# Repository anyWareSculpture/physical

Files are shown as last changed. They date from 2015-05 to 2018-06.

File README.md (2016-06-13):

# physical
Physical computing aspects of anyWare (firmware, electronics)

## arduino

The Arduino sketches share some common code.
However, there are no good mechanism for sharing code when using the IDE.

Our workaround for now is to keep shared code in the common/ folder
and copy the files from there into each sketch folder.
Not nice, but the result is self-contained sketches.

We use the Teensy 3.x for parts of the system. Download the Teensyduino add-on from here: https://www.pjrc.com/teensy/td_download.html
Note: We don't need any libraries installed with Teensy as we include our own.

Note: As of December 2015, our code doesn't compile with Arduino >= 1.6.6.

### Programming Info

**PanelInterface:**

The 3 panel interfaces run off separate Arduinos running the same sketch, but with different configurations.

* Open PanelInterface/configuration.h
* Enable the controller you want to program; A, B or C
* Compile & Upload
* Repeat for all controllers

### Test sketches

These are just for hardware testing

### Test games

These are basic self-contained game sketches, for playtesting in isolation

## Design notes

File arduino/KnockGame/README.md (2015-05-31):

# KnockGame

This sketch is responsible for the **Handshake** and **Knock** interfaces.

# External Libraries

## SerialCommand

https://github.com/kroimon/Arduino-SerialCommand

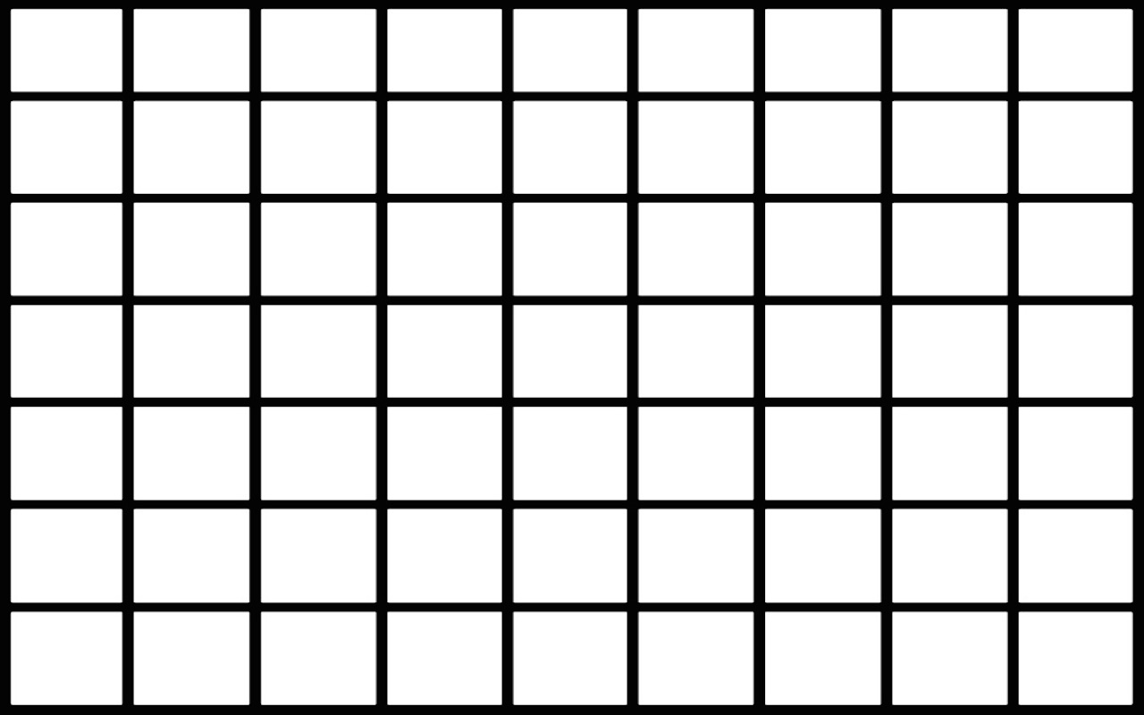
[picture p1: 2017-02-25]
RaspberryPi/grid.jpg

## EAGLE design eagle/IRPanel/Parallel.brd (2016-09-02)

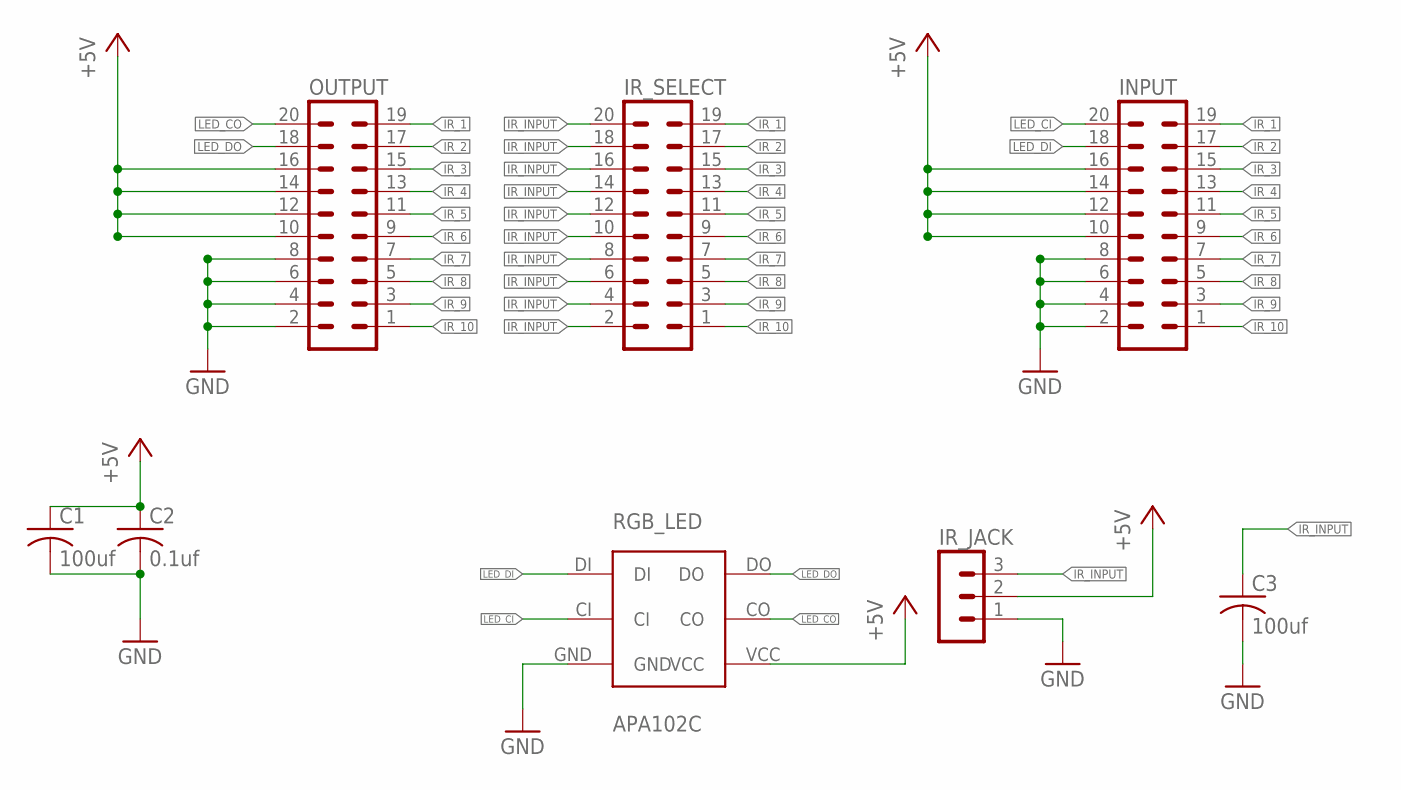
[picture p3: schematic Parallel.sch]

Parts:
C1, C3: 100uf; C0805
C2: 0.1uf; C0603
INPUT: MA10-2
IR_JACK: MA03-1
IR_SELECT: MA10-2
OUTPUT: MA10-2
RGB_LED: APA102C

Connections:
+5V: C1.1, C2.1, INPUT.10, INPUT.12, INPUT.14, INPUT.16, IR_JACK.2, OUTPUT.10, OUTPUT.12, OUTPUT.14, OUTPUT.16, RGB_LED.VCC
GND: C1.2, C2.2, C3.2, INPUT.2, INPUT.4, INPUT.6, INPUT.8, IR_JACK.1, OUTPUT.2, OUTPUT.4, OUTPUT.6, OUTPUT.8, RGB_LED.GND
IR_1: INPUT.19, IR_SELECT.19, OUTPUT.19
IR_2: INPUT.17, IR_SELECT.17, OUTPUT.17
IR_3: INPUT.15, IR_SELECT.15, OUTPUT.15
IR_4: INPUT.13, IR_SELECT.13, OUTPUT.13
IR_5: INPUT.11, IR_SELECT.11, OUTPUT.11
IR_6: INPUT.9, IR_SELECT.9, OUTPUT.9
IR_7: INPUT.7, IR_SELECT.7, OUTPUT.7
IR_8: INPUT.5, IR_SELECT.5, OUTPUT.5
IR_9: INPUT.3, IR_SELECT.3, OUTPUT.3
IR_10: INPUT.1, IR_SELECT.1, OUTPUT.1
IR_INPUT: C3.1, IR_JACK.3, IR_SELECT.2, IR_SELECT.4, IR_SELECT.6, IR_SELECT.8, IR_SELECT.10, IR_SELECT.12, IR_SELECT.14, IR_SELECT.16, IR_SELECT.18, IR_SELECT.20
LED_CI: INPUT.20, RGB_LED.CI
LED_CO: OUTPUT.20, RGB_LED.CO
LED_DI: INPUT.18, RGB_LED.DI
LED_DO: OUTPUT.18, RGB_LED.DO

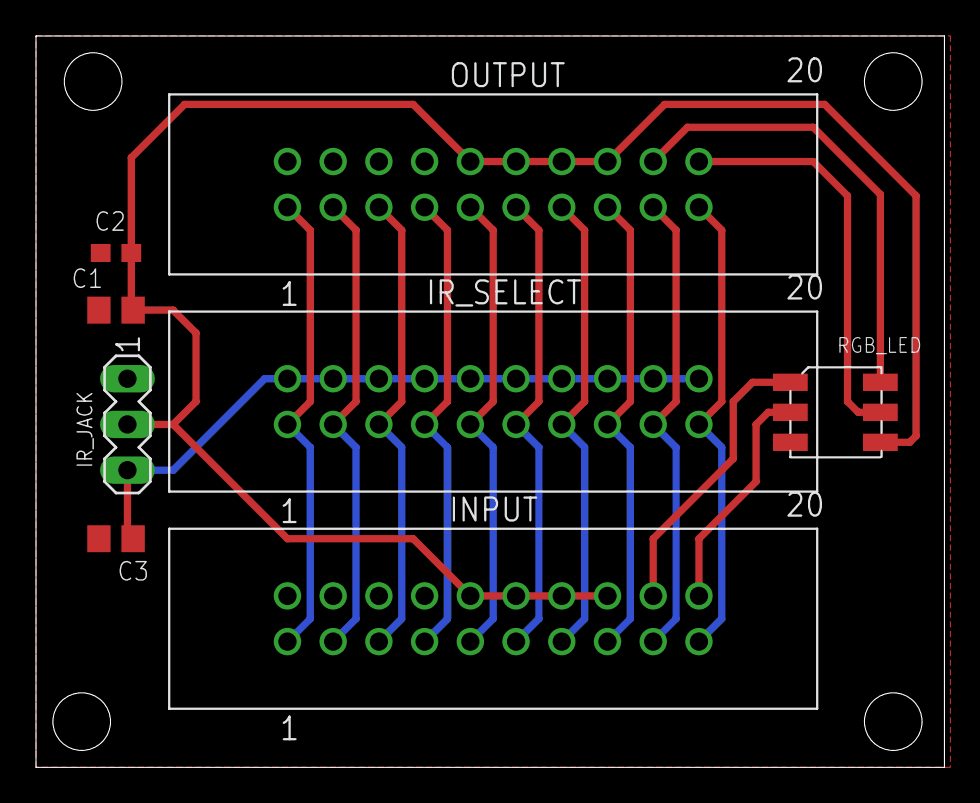
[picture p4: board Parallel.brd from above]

Board: 2 copper layers, 50.5 x 40.6 mm, 8 parts (0 on the bottom side), 17 nets.

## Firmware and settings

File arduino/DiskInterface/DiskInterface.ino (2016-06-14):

// Yes, this is actually -*-c++-*-

/*!
  This sketch is responsible for the Disk game

  Example commands:

HELLO
DISK-RESET
DISK 0 POS 10 DIR 1
DISK 1 POS 50 DIR 1
DISK 2 POS 60 DIR 1
DISK 0 DIR 0 USER 1
DISK 0 DIR 1 USER 1
DISK 0 DIR -1 USER 1
DISK 0 DIR 1 USER 1
DISK 1 DIR -1 USER 1
DISK 2 DIR 1 USER 1

*/

#if !defined(__MK20DX256__)
#error Oops!  Make sure you have 'Teensy 3.1' selected from the 'Tools -> Board' menu.
#endif

#include "DiskInterface.h"
#include "anyware_serial.h"

// Set to 1 to start in debug mode
#define DEBUG_MODE 0

// All disks
const int STEPS_PER_REVOLUTION = 180;

// Bottom disk
const int DISK0_STEP_SENSOR = 2;
const int DISK0_ENC_A = 17;
const int DISK0_ENC_B = 16;
const int DISK0_MOTOR_A = 21;
const int DISK0_MOTOR_B = 20;
const int DISK0_TICKS_PER_STEP = 36;

// Middle disk
const int DISK1_STEP_SENSOR = 1;
const int DISK1_ENC_A = 11;
const int DISK1_ENC_B = 12;
const int DISK1_MOTOR_A = 3;
const int DISK1_MOTOR_B = 5;
const int DISK1_TICKS_PER_STEP = 56;

// Top disk
const int DISK2_STEP_SENSOR = 0;
const int DISK2_ENC_A = 19;
const int DISK2_ENC_B = 18;
const int DISK2_MOTOR_A = 22;
const int DISK2_MOTOR_B = 23;
const int DISK2_TICKS_PER_STEP = 36;

// Globals

const uint8_t MAGNET_SENSITIVITY = 160;

#define USER0_STR "0"
#define USER1_STR "1"
#define USER2_STR "2"

struct Disk {
  int id;
  int stepSensor;
  int enca, encb;
  int motorA,motorB;
  uint16_t ticksPerStep;

  void (*enca_isr)();
  void (*encb_isr)();
  void (*step_isr)();

  bool enca_val;
  bool encb_val;
  bool step_val;

  int16_t targetPosition;
  uint16_t actualPosition;
  int16_t tickCount;
  int16_t lastTickCount;
  int16_t tickDir;
  int16_t stepCount;

  Direction direction;

  static const int DISK_READY = 0;
  static const int DISK_HOMING = 1;
  int state;
  uint8_t home;

  Disk(int diskid, int stepsensor, int enca, int encb, int ma, int mb, uint16_t ticks,
       void (*enca_isr)(), void (*encb_isr)(), void (*step_isr)()) :
    id(diskid), stepSensor(stepsensor), enca(enca), encb(encb), motorA(ma), motorB(mb),
    ticksPerStep(ticks),
    enca_isr(enca_isr), encb_isr(encb_isr), step_isr(step_isr),
    enca_val(false), encb_val(false),
    actualPosition(0), tickCount(0), tickDir(DIR_OFF), lastTickCount(0), stepCount(0),
    direction(DIR_OFF), state(DISK_READY), home(0)
  {
  }

  void setup() {
    pinMode(motorA, OUTPUT);
    pinMode(motorB, OUTPUT);
    pinMode(enca, INPUT_PULLUP);
    pinMode(encb, INPUT_PULLUP);
    pinMode(stepSensor, INPUT_PULLUP);
    enca_val = digitalRead(enca);
    encb_val = digitalRead(encb);
    reset();
    attachInterrupt(enca, enca_isr, CHANGE);
    attachInterrupt(encb, encb_isr, CHANGE);
    attachInterrupt(stepSensor, step_isr, CHANGE);
  }

  void reset() {
    targetPosition = -1;
    Serial.println("Reset");
    direction = DIR_OFF;
  }

  inline uint16_t calcPos() {
    return (stepCount * 360 / STEPS_PER_REVOLUTION + tickCount * (360 / STEPS_PER_REVOLUTION) / ticksPerStep + 360)%360;
  }
  
  inline void handleEncA() {
    enca_val = digitalRead(enca);
    if (enca_val != encb_val) {
      tickCount++;
      tickDir = DIR_CCW;
    }
    else {
      tickCount--;
      tickDir = DIR_CW;
    }
  }

  inline void handleEncB() {
    encb_val = digitalRead(encb);
    if (enca_val == encb_val) {
      tickCount++;
      tickDir = DIR_CCW;
    }
    else {
      tickCount--;
      tickDir = DIR_CW;
    }
  }

  inline void handleStep() {
    if (abs(tickCount) > ticksPerStep * 2) {
      if (tickCount > 0) stepCount = 0;
      else stepCount = STEPS_PER_REVOLUTION-3;
      tickCount = 0;
      if (state == DISK_HOMING) home++;
    }
    else {
      if (tickDir == DIR_CCW) stepCount++;
      else if (tickDir == DIR_CW) stepCount--;
      lastTickCount = tickCount;
      tickCount = 0;
    }
  }

  void setState(int s) {
    state = s;
    Serial.print("DISK-STATE ");Serial.print(id);
    switch (state) {
    case DISK_READY:
      Serial.println(" ready");
      direction = DIR_OFF;
      break;
    case DISK_HOMING:
      Serial.println(" homing");
      setTargetPosition(-1, DIR_CW);
      home = 0;
      break;
    }
  }

  int getState() {
    return state;
  }

  /*!
    if pos is unspecified (-1), just move in the given direction
   */
  void setTargetPosition(int pos, Direction dir) {
    targetPosition = pos;
    direction = dir;
  }

  int getPosition() {
    return actualPosition;
  }

  void motorMove() {
    switch (direction) {
    case DIR_CW:
      digitalWrite(motorA, HIGH); 
      digitalWrite(motorB, LOW); //1A high and 2A low = turn right
      break;
    case DIR_CCW:
      digitalWrite(motorA, LOW); 
      digitalWrite(motorB, HIGH); //1A low and 2A high = turn left  
      break;
    default:
      digitalWrite(motorA, LOW); 
      digitalWrite(motorB, LOW); //1A low and 2A low = off
      break;
    }
  }

  void handleCount() {
    uint16_t pos = calcPos();
    if (pos != actualPosition) {
      actualPosition = pos;
      if (global_state == STATE_READY) {
        Serial.print("DISK ");Serial.print(id);
        Serial.print(" POS ");Serial.print(actualPosition);
        Serial.print(" DIR ");Serial.print(direction);
        Serial.print(" STEPS ");Serial.print(stepCount);
        Serial.print(" TICKS ");Serial.print(tickCount);
        Serial.println();
      }
    }
  }

  void manage() {
    if (state == DISK_HOMING) {
      if (home == 1) {
        direction = DIR_CCW;
      }
      else if (home == 2) {
        actualPosition = 0;
        setState(DISK_READY);
      }
    }
    else if (state == DISK_READY) {
      handleCount();

      if (targetPosition >= 0 && actualPosition == targetPosition) {
        Serial.println("at wanted position");
        direction = DIR_OFF;
        targetPosition = -1;
      }
    }
    motorMove();
  }
};

extern Disk disk[3];

void disk0a_isr() {
  cli();
  disk[0].handleEncA();
  sei();
}
void disk0b_isr() {
  cli();
  disk[0].handleEncB();
  sei();
}
void disk0step_isr() {
  cli();
  disk[0].handleStep();
  sei();
}
void disk1a_isr() {
  cli();
  disk[1].handleEncA();
  sei();
}
void disk1b_isr() {
  cli();
  disk[1].handleEncB();
  sei();
}
void disk1step_isr() {
  cli();
  disk[1].handleStep();
  sei();
}
void disk2a_isr() {
  cli();
  disk[2].handleEncA();
  sei();
}
void disk2b_isr() {
  cli();
  disk[2].handleEncB();
  sei();
}
void disk2step_isr() {
  cli();
  disk[2].handleStep();
  sei();
}

Disk disk[3] = {
  Disk(0, DISK0_STEP_SENSOR, DISK0_ENC_A, DISK0_ENC_B, DISK0_MOTOR_A, DISK0_MOTOR_B, DISK0_TICKS_PER_STEP, &disk0a_isr, &disk0b_isr, &disk0step_isr),
  Disk(1, DISK1_STEP_SENSOR, DISK1_ENC_A, DISK1_ENC_B, DISK1_MOTOR_A, DISK1_MOTOR_B, DISK1_TICKS_PER_STEP, &disk1a_isr, &disk1b_isr, &disk1step_isr),
  Disk(2, DISK2_STEP_SENSOR, DISK2_ENC_A, DISK2_ENC_B, DISK2_MOTOR_A, DISK2_MOTOR_B, DISK2_TICKS_PER_STEP, &disk2a_isr, &disk2b_isr, &disk2step_isr)
};

void setGlobalState(int state) {
  if (state == STATE_HOMING) {
    global_state = STATE_BLOCKED; // Don't output anything before we start homing
    startHoming();
  }
  else {
    global_state = state;
  }
}

void startHoming() {
  global_state = STATE_HOMING;
  for (int i=0;i<3;i++) disk[i].setState(Disk::DISK_HOMING);
}

void manageDiskGame() {
  if (global_state == STATE_HOMING) {
    bool homed = true;
    for (int i=0;i<3;i++) {
      if (disk[i].getState() == Disk::DISK_HOMING) homed = false;
    }
    if (homed) {
      setGlobalState(STATE_READY);
    }
  }

  for (int i=0;i<3;i++) disk[i].manage();
}

void setup()
{
  Serial.begin(115200);

  resetInterface(DEBUG_MODE);
  setupCommands();
}

// Reset everything to initial state
void resetInterface(bool debug)
{
  for (int i=0;i<3;i++) disk[i].setup();
  setGlobalState(STATE_READY);

  global_debug = debug;

  Serial.println();
  Serial.println("HELLO disk");
  if (global_debug) Serial.println("DEBUG disk");
  printCommands();
}

void initInterface() {
}

/*!
  DISK-RESET

  Home the disks and afterwards go into "ready" mode.
*/
void do_disk_reset()
{
  for (int i=0;i<3;i++) disk[i].reset();
  setGlobalState(STATE_HOMING);
}

/*!
  pos can be unspecified (-1)
*/
void do_disk(uint8_t diskid, int userid, int pos, Direction dir)
{
  // Ignore pos/dir commands while homing
  if (disk[diskid].getState() == Disk::DISK_READY) {
    disk[diskid].setTargetPosition(pos, dir);
  }
}

void loop()
{
  handleSerial();

  manageDiskGame();
}

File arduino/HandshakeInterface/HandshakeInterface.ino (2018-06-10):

// Yes, this is actually -*-c++-*-

/*!
  This sketch is responsible for the Handshake interactions


  Example commands:
HANDSHAKE 1 0
HANDSHAKE 1 1
HANDSHAKE 1 2

PANEL-SET 5 0 100 sculpture1 easein
PANEL-SET 5 1 100 sculpture2 easein
PANEL-SET 5 2 100 sculpture3 easein
PANEL-SET 5 3 100 sculpture3 easein
PANEL-SET 5 3 0 sculpture3 easein
PANEL-SET 5 3 0 white easein
PANEL-PULSE 5 3 100 white sleep
PANEL-SET 6 0 100 sculpture1
PANEL-SET 6 1 100 sculpture1
PANEL-SET 6 2 100 sculpture1
PANEL-SET 6 012 100 sculpture1

PANEL-SET 3 0 100 rgb0
PANEL-SET 3 1 100 rgb1

*/

#if !defined(__AVR_ATmega1280__) && !defined(__AVR_ATmega2560__)
  #error Oops!  Make sure you have 'Arduino/Genuino Mega or Mega 2560' selected from the 'Tools -> Board' menu.
#endif

#include "HandshakeInterface.h"
#include <Wire.h> // Needed to make Arduino add the corresponding include path
#include "TouchSensor.h"
#include "Pixel.h"
#include "LEDStrip.h"
#include "anyware_serial.h"

// Set to 1 to start in debug mode
#define DEBUG_MODE 0

#define TOUCH_SENSOR_PIN  31
#define VIB_PIN  11
#define LED1_PIN  8
#define LED2_PIN  9
#define LED3_PIN  10

#define RED0_PIN 4
#define GRN0_PIN 3
#define BLU0_PIN 2
#define RED1_PIN 7
#define GRN1_PIN 6
#define BLU1_PIN 5

uint8_t highPowerLEDs[] = { LED1_PIN, LED2_PIN, LED3_PIN };
bool highPowerOnState[] = { false, false, false };

uint8_t rgbStripPins[2][3] = {
  { RED0_PIN, GRN0_PIN, BLU0_PIN },
  { RED1_PIN, GRN1_PIN, BLU1_PIN },
};

// Tuned for proximity sensor
#define TOUCH_THRESHOLD   50
#define	RELEASE_THRESHOLD 30

// I2C pins:
// SDA - A4
// SCL - A5

TouchSensor touch(TOUCH_SENSOR_PIN);

// How many panels are attached to the Arduino?
#define STRIP_LEDS  4
CRGB leds[STRIP_LEDS];
Pixel pixels[STRIP_LEDS] = {
  Pixel(5, 0),
  Pixel(5, 1),
  Pixel(5, 2),
  Pixel(5, 3),
};
LEDStrip<SPI_DATA, SPI_CLOCK> strip(STRIP_LEDS, leds, pixels);

void setup()
{ 
  Serial.begin(115200);

  setupCommands();
  resetInterface(DEBUG_MODE);
}

void initInterface() {
}

// Reset everything to initial state
void resetInterface(bool debug)
{
  touch.setup();
  for (int i=0;i<LEDStripInterface::getNumStrips();i++) LEDStripInterface::getStrip(i).setup();
  LEDStripInterface::setAllColors(BLACK);

  digitalWrite(VIB_PIN, 0);
  pinMode(VIB_PIN, OUTPUT);
  for (uint8_t i=0;i<3;i++) {
    digitalWrite(highPowerLEDs[i], !highPowerOnState[i]);
    pinMode(highPowerLEDs[i], OUTPUT);
  }


  global_debug = debug;
  Serial.println();
  Serial.println("HELLO handshake V1.4");
  if (global_debug) Serial.println("DEBUG handshake");
  printCommands();
}

void do_panel_set(uint8_t strip, PanelSet panels, uint8_t intensity, const CRGB &color, AnywareEasing::EasingType easing, uint16_t duration)
{
  CRGB newcol = applyIntensity(color, intensity);

  if (strip == 3) {
    // Handle RGB strips
    for (uint8_t panel=0;panel<2;panel++) {
      if (panels.get(panel)) {
	for (uint8_t c=0;c<3;c++) {
	  analogWrite(rgbStripPins[panel][c], 255-newcol[c]);
	}
      }
    }
    return;
  }
  if (strip == 6) {
    for (uint8_t panel=0;panel<3;panel++) {
      if (panels.get(panel)) {
	// Handle high-power LEDs
	uint8_t pin = highPowerLEDs[panel];
	digitalWrite(pin, intensity == 0 ? !highPowerOnState[panel] : highPowerOnState[panel]);
      }
    }
    return;
  }

  for (uint8_t panel=0;panel<STRIP_LEDS;panel++) {
    if (panels.get(panel)) {
      const Pair &p = LEDStripInterface::mapToLED(strip, panel);
      if (p.stripid < 0 || p.pixelid < 0) {
	printError(F("client error"), F("Strip or panel out of range"));
	Serial.print(p.stripid);Serial.print(" ");Serial.println(p.pixelid);
	return;
      }
      LEDStripInterface &s = LEDStripInterface::getStrip(p.stripid);
      if (easing == AnywareEasing::BINARY) {
	s.setColor(p.pixelid, newcol);
      }
      else {
	s.ease(p.pixelid, easing, newcol, duration);
      }
    }
  }
  if (easing == AnywareEasing::BINARY) {
    FastLED.show();
  }
}

void do_panel_pulse(uint8_t strip, PanelSet panels, uint8_t intensity, const CRGB &color, AnywareEasing::EasingType  easing, uint16_t duration)
{
  do_panel_set(strip, panels, intensity, color, easing, duration);
}

void do_panel_intensity(uint8_t strip, uint8_t intensity)
{
  // FIXME: We don't currently support per-strip intensity, only global intensity
  FastLED.setBrightness(255*intensity/100);
  FastLED.show();
}

void do_handshake(uint8_t numusers)
{
  analogWrite(VIB_PIN, 255 * numusers / 3);
}

// Detect and send handshake
void handleHandshake()
{
  if (touch.update()) {
    bool active = touch.getStatus();
    Serial.print("HANDSHAKE ");
    Serial.println(active);
  }
}

uint32_t animPrevTickTime = 0;
void handleAnimations()
{
  uint32_t currtime = millis();

  if (currtime - animPrevTickTime >= 1) { // tick
    animPrevTickTime = currtime;
    LEDStripInterface::applyEasings();
  }
}

void loop()
{
  handleSerial();
  handleHandshake();
  handleAnimations();
}

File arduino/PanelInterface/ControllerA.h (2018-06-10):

#ifdef ANYWARE_MAIN

// Pins
const int IRPin1 = 2;  // IR pins
const int IRPin2 = 3;
const int IRPin3 = 4;
const int IRPin4 = 5;
const int IRPin5 = 6;
const int IRPin6 = 7;
const int IRPin7 = 8;
const int IRPin8 = 9;
const int IRPin9 = 14;
const int IRPin10 = 15;

#define STRIP_LEDS 10
CRGB strip_leds[STRIP_LEDS];
Pixel strip_pixels[STRIP_LEDS] = {
  Pixel(STRIPID, 9),
  Pixel(STRIPID, 8),
  Pixel(STRIPID, 7),
  Pixel(STRIPID, 6),
  Pixel(STRIPID, 5),
  Pixel(STRIPID, 4),
  Pixel(STRIPID, 3),
  Pixel(STRIPID, 2),
  Pixel(STRIPID, 1),
  Pixel(STRIPID, 0)
};
LEDStrip<SPI_DATA, SPI_CLOCK> strip(STRIP_LEDS, strip_leds, strip_pixels);

#define STRIP_SENSORS 10
Sensor strip_sensors[STRIP_SENSORS] = {
  Sensor(STRIPID, 9, IRPin1),
  Sensor(STRIPID, 8, IRPin2),
  Sensor(STRIPID, 7, IRPin3),
  Sensor(STRIPID, 6, IRPin4),
  Sensor(STRIPID, 5, IRPin5),
  Sensor(STRIPID, 4, IRPin6),
  Sensor(STRIPID, 3, IRPin7),
  Sensor(STRIPID, 2, IRPin8),
  Sensor(STRIPID, 1, IRPin9),
  Sensor(STRIPID, 0, IRPin10)
};
DiscreteSensors sensors(STRIP_SENSORS, strip_sensors);

#endif

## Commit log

2015-06-04 Added buzzer on EXIT knock, print message on unknown INIT command
    [KnockGame.ino]
2015-06-04 Write newline before HELLO to avoid garbage
    [KnockGame.ino]
2015-06-14 Require Arduino Mega
2015-06-22 Added FIXME's for easings
    [HandshakeInterface.ino]
2015-06-29 Implemented easing for RGB LEDs
2015-08-29 Added new Sharp IR sensor
2015-08-29 Replaced NeoPixels with APA102 DotStar LEDS using FastLED library
2015-08-29 Ported to new Sharp sensors and FastLED library
2015-08-29 Ported to new LEDs and new Sharp sensors
2015-08-30 Reintroduced debounding of Sharp sensors to work around sensitivity issues
2015-08-30 Updated pinout to not conflict with FastLED SPI pins
2015-09-13 Rewrite LED and sensor interfaces to allow for more strips per controller, and separated sensors from leds as some strips will not have built-in sensors
    [configuration.h]
2015-09-13 Ported to new LED and sensor interface
2015-09-14 Require Teensy 3.1
2015-09-14 Added printCommand()
2015-09-14 bugfix: missing space in regexp
    [ControllerA.h]
2015-09-14 Added printCommand(), sync
    [configuration.h]
2015-09-20 Removed the G
    [configuration.h]
2015-09-26 TouchSensor doesn't (yet) belong in common due to compilation issues with the Wire library
2015-09-26 Deprecated IDENTITY, INIT and RESET, introduced HELLO command
    [CommonCommands.cpp, DiskCommands.cpp, DiskInterface.ino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]
2015-09-26 Added 4th LED to strip, fixed colorwipe
2015-11-27 Added note about Teensy
2015-11-27 Introduced BLOCKED state to avoid output of positions during homing
    [DiskInterface.ino]
2015-11-27 Sculpture-centric order of LED strip
2015-11-27 Don't touch perimeter LEDs
2015-11-27 Added vibration and high-power LEDs
    [HandshakeCommands.cpp, HandshakeInterface.ino]
2015-11-29 Better calibrated ticks per revolution
2015-12-22 Don't output HIT TICKS unless we're ready and moving, to avoid noisy serial output
    [DiskInterface.ino]
2016-06-13 Removed panel commands and LED control
2016-06-13 Updated to use new disk sensors; ring of IR steps rather than a single hall effect sensor
2016-06-14 Ignore pos/dir commands while homing, as this could put the interface into an unusable state (stop while homing)
2016-09-02 IR panel design from Mo
    [Parallel.brd, Parallel.sch]
2016-11-14 Updated configuration to new board design
2016-11-19 Added IR Panel Shield schematics
    [Ir-Panel-Shield.sch]
2016-11-19 Added handshake schematics
    [handshake.sch]
2016-11-23 Simple sketch to test all high power LEDs in ON state
2016-12-10 Print warning if wrong MCU is selected
    [HandshakeInterface.ino]
2016-12-10 Switch LED pins, print warning if wrong MCU is selected
2016-12-10 New test sketch testing both high power LEDs and RGB stips
2017-01-26 Adjusted to new physical configuration, print active panel IDs
2017-02-09 Debounced shutdown button
2017-02-10 Schematic for soft power button
    [Soft Poweroff.sch]
2017-02-10 Moved to its own folder
    [SoftPoweroff.sch]
2017-02-18 Bugfix: Respect intensity for RGB strip. V1.2.1
    [HandshakeInterface.ino]
2017-05-07 Raspberry startup scripts
2018-04-22 Support double-click to reboot
    [pishutdown.py]
2018-05-26 Bugfix: Change of color during fade caused the LED to turn blue
2018-06-10 Simplified configuration specification
    [configuration.h]
2018-06-10 Bugfix for virtual light
    [HandshakeCommands.cpp]

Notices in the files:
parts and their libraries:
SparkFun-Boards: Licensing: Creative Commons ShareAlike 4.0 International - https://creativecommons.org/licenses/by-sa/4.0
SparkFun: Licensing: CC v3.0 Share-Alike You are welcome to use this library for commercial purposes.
